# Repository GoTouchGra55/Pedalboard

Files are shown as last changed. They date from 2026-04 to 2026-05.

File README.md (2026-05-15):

# Multi-Effects Pedal Board

A custom multi-effects guitar pedal board combining several audio effects into one compact unit. Designed primarily as a learning project to explore analog audio circuits, signal processing, and embedded control systems (obv).

Also I needed effects pedals and those things are absurdly expensive ;')

---

## Features

- **Distortion & Overdrive** – From mild warmth to heavy saturation
- **Chorus** – Thickens and widens the sound
- **Tremolo** – Rhythmic volume modulation
- **Delay** – Adds echo and spatial depth

---

##  Signal Chain

Input -> Overdrive/Distortion -> Chorus -> Tremolo -> Delay -> Output

> _Note: Signal order can be adjusted depending on design preferences._

---

## Power Requirements

- **Input Voltage:** 9V DC (center-negative)
- **Power Supply:** Regulated recommended
- Includes onboard regulation and decoupling for noise reduction

---

## Hardware Overview

- Individual circuits for each effect
- Decoupling capacitors for stable operation

---

## I/O

- **Input Jack:** 1/4" mono
- **Output Jack:** 1/4" mono
- **DC Jack:** 9V input

---

## 3D View
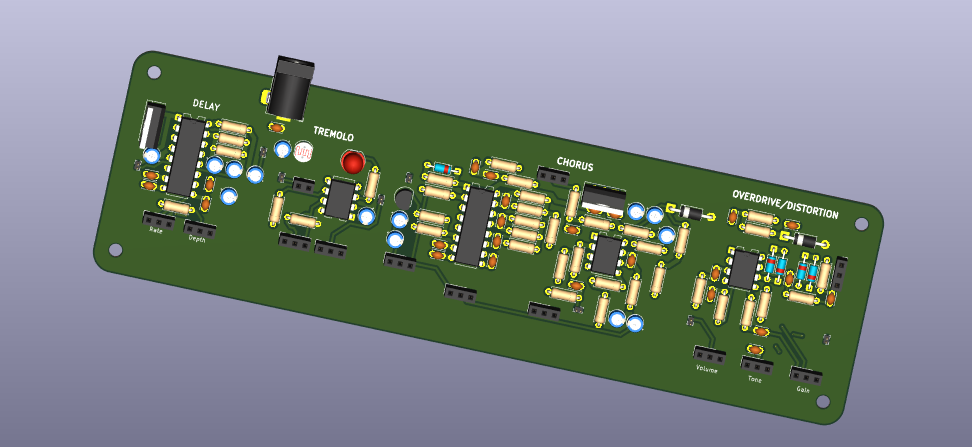
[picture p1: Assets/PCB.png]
PCB

---

## Routing
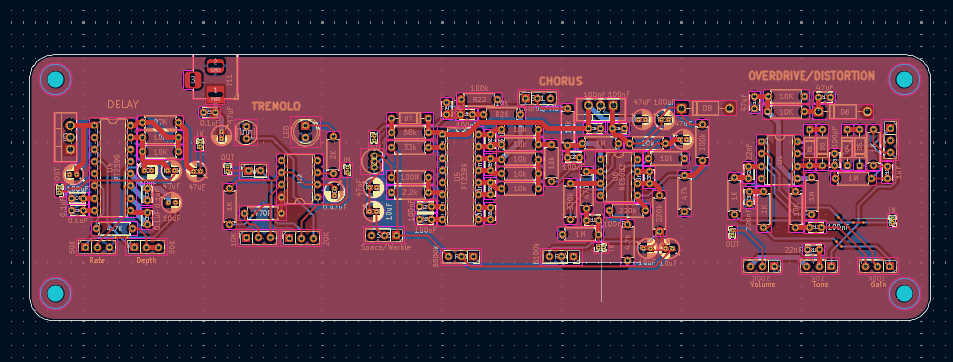
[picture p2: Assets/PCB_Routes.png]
PCB Routing


## BOM

| Component | Purpose | Qty | Total Cost (USD) | Distributor |
|---|---|---:|---:|---|
| Stomp Switch | Toggle each effect | 1 | 25.53 | Daraz Nepal |
| 50k Potentiometer | Used in circuit | 1 | 7.38 | Daraz Nepal |
| 20k Potentiometer | Used in circuit | 1 | 5.08 | Daraz Nepal |
| 2k Potentiometer | Used in circuit | 1 | 5.22 | Daraz Nepal |
| 10k Potentiometer | Used in circuit | 1 | 0.63 | Daraz Nepal |
| 100k Potentiometer | Used in circuit | 1 | 1.24 | Daraz Nepal |
| 500k Potentiometer | Used in circuit | 1 | 5.08 | Daraz Nepal |
| B100k Potentiometer | Used in circuit | 1 | 0.50 | Daraz Nepal |
| B500K Potentiometer | Used in circuit | 1 | 0.50 | Daraz Nepal |
| PCB | Houses all components | 1 | 8.20 | JLCPCB |
| DC Barrel Jack | Power input connector | 1 | 0.44 | Daraz Nepal |
| 1uF Capacitor | Charge storage/filtering | 1 | 0.88 | Daraz Nepal |
| 220nF Capacitor | Charge storage/filtering | 1 | 0.88 | Daraz Nepal |
| 100nF Capacitor | Charge storage/filtering | 1 | 1.82 | Daraz Nepal |
| Ceramic Capacitors Kit | Misc capacitor assortment | 1 | 7.91 | Daraz Nepal |
| Capacitor Kit | General purpose capacitors | 1 | 2.97 | Daraz Nepal |
| 2.2M Resistor | Current limiting | 1 | 0.66 | Daraz Nepal |
| Resistor Kit | General purpose resistors | 1 | 3.92 | Daraz Nepal |
| LDR | Tremolo light-dependent resistance | 1 | 2.27 | Daraz Nepal |
| LED | Status indication | 1 | 0.87 | Daraz Nepal |
| Voltage Regulator (7805) | Voltage regulation | 1 | 1.31 | Daraz Nepal |
| PT2399 IC | Delay/chorus processing IC | 1 | 2.36 | Daraz Nepal |
| LM555 Timer | PWM generation for tremolo | 1 | 2.00 | Daraz Nepal |
| NE5532 Op Amp | Chorus effect op amp | 1 | 1.78 | Daraz Nepal |
| TL072 | Gain/effects op amp | 1 | 1.69 | Daraz Nepal |
| Diode | One-way current flow | 1 | 0.40 | Daraz Nepal |
| Schottky Diode | Fast low-drop diode | 1 | 0.93 | Daraz Nepal |
| 1N4148 Diode | Signal diode | 1 | 0.27 | Daraz Nepal |
| 2N3904 Transistor | Signal filtering/amplification | 1 | 0.63 | Daraz Nepal |
| Guitar Jack Socket | Guitar/amp I/O connection | 2 | 2.07 | Daraz Nepal |

## Estimated Total Cost

**~$94.54 USD**

> Note: Prices may vary depending on shipping, stock availability, and quantity ordered.

---

## Suppliers

- Daraz Nepal
- JLCPCB

---

## Notes

- Passive component kits (capacitors/resistors) include multiple values and quantities.
- Potentiometer values may vary depending on the final pedal circuit tuning.
- PCB pricing is estimated from JLCPCB prototype manufacturing quotes.

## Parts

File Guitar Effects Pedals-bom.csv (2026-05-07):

Name | Purpose | Quantity | Total Cost (USD) | Link | Distributor
Stomp Switch | To toggle each effect | 1 | 25.53 | https://www.daraz.com.np/products/miwayer-510pcs-3pdt-footswitch-latching-stomp-switch-triple-pole-double-throw-9-pin-latching-push-button-for-diy-guitar-peda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 | Daraz Nepal
50k Potentiometer | Used in circuit | 1 | 7.38 | https://www.daraz.com.np/products/5pcs-wh148-3pin-20mm-potentiometer-b1k-b2k-b5k-b10k-b20k-b50k-b100k-b250k-b500k-b1m-1k-2k-5k-10k-20k-50k-100k-250k-500k-1m-i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 | Daraz Nepal
20k potentiometer | Used in circuit | 1 | 5.08 | https://www.daraz.com.np/products/5pcs-wh148-3pin-20mm-potentiometer-b1k-b2k-b5k-b10k-b20k-b50k-b100k-b250k-b500k-b1m-1k-2k-5k-10k-20k-50k-100k-250k-500k-1m-i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 | Daraz Nepal
2k Potentiometer | Used in circuit | 1 | 5.22 | https://www.daraz.com.np/products/5pcs-wh148-3pin-20mm-potentiometer-b1k-b2k-b5k-b10k-b20k-b50k-b100k-b250k-b500k-b1m-1k-2k-5k-10k-20k-50k-100k-250k-500k-1m-i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 | Daraz Nepal
10k Potentiometer | Used in circuit | 1 | 0.63 | https://www.daraz.com.np/products/10k-potentiometer5-pcs-i135751077-s1060884241.html?c=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 | Daraz Nepal
100k Potentiometer | Used in circuit | 1 | 1.24 | https://www.daraz.com.np/products/potentiometer-1k5k10k100k-5-pcs-i125469178-s1134645078.html?c=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 | Daraz Nepal
500k Potentiometer | Used in circuit | 1 | 5.08 | https://www.daraz.com.np/products/5pcs-wh148-3pin-20mm-potentiometer-b1k-b2k-b5k-b10k-b20k-b50k-b100k-b250k-b500k-b1m-1k-2k-5k-10k-20k-50k-100k-250k-500k-1m-i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 | Daraz Nepal
B100k Potentiometer | Used in circuit | 1 | 0.50 | https://www.daraz.com.np/products/2pcslot-wh148-b1k-b2k-b5k-b10k-b20k-b50k-b100k-b500k-3pin-15mm-shaft-amplifier-dual-stereo-potentiometer-1k-2k-5k-10k-50k-10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 | Daraz Nepal
B500K Potentiometer | Used in circuit | 1 | 0.50 | https://www.daraz.com.np/products/2pcslot-wh148-b1k-b2k-b5k-b10k-b20k-b50k-b100k-b500k-3pin-15mm-shaft-amplifier-dual-stereo-potentiometer-1k-2k-5k-10k-50k-10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 | Daraz Nepal
PCB | To house all the components | 1 | 8.20 | https://cart.jlcpcb.com/quote?spm=jlcpcb.Public.2006 | JLCPCB
DC Barrel Jack | To connect the board to a power supply | 1 | 0.44 | https://www.daraz.com.np/products/2-pcs-set-universal-dc-female-jack-connector-5v9v12v-i123504998-s1033563120.html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 | Daraz Nepal
1uF Capacitor | To store charge | 1 | 0.88 | https://www.daraz.com.np/products/100pcs-50v-monolithic-ceramic-capacitor-10pf-10uf-22pf-47nf-220nf-1nf-47uf-1uf-100nf-330nf-01uf-102-104-105-106-103-473-334-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 | Daraz Nepal
220nF capacitor | To store charge | 1 | 0.88 | https://www.daraz.com.np/products/100pcs-50v-monolithic-ceramic-capacitor-10pf-10uf-22pf-47nf-220nf-1nf-47uf-1uf-100nf-330nf-01uf-102-104-105-106-103-473-334-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 | Daraz Nepal
100nF Capactor | To store charge | 1 | 1.82 | https://www.daraz.com.np/products/100pcs-ceramic-capacitor-50v-1pf-100nf-01uf-104-47pf-10pf-22pf-33pf-47pf-100pf-101-220pf-10nf-330pf-470pf-1nf-103-47nf-473-i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 | Daraz Nepal
Ceramic capacitors | To store charge | 1 | 7.91 | https://www.daraz.com.np/products/7-value-components-big-kit-35mm-led-diodes-and-triodes-ceramics-electrolytic-ceramics-capacitors-metal-film-resistors-i41669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 | Daraz Nepal
Capacitors | To store charge | 1 | 2.97 | https://www.daraz.com.np/products/15-200-01-220-i182333371-s1214207392.html?c=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 | Daraz Nepal
2.2M Resistor | To resist current | 1 | 0.66 | https://www.daraz.com.np/products/50pcs-12w-1-metal-film-resistor-1r22m-100r-220r-330r-1k-15k-22k-33k-47k-10k-22k-47k-100k-100-220-330-1k5-2k2-3k3-4k7-ohm-i18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 | Daraz Nepal
Resistors | To resist current | 1 | 3.92 | https://www.daraz.com.np/products/30-kinds-14w-resistance-1-accuracy-metal-film-resistor-pack-600pcs-in-1-set-i156026363-s1122597672.html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 | Daraz Nepal
LDR | Used to change resistance according to light source for tremolo effect | 1 | 2.27 | https://www.daraz.com.np/products/50-5528-5-ldr5528-i182298738-s1214149089.html?c=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 | Daraz Nepal
LED | To indicate status of each section | 1 | 0.87 | https://www.daraz.com.np/products/led-5mm-mix-colors-pack-of-50-pcs-i129083282-s1037089095.html?c=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 | Daraz Nepal
Regulators | To regulate voltage | 1 | 1.31 | https://www.daraz.com.np/products/10pcs-l7805cv-to220-7805-l7805-lm7805-mc7805-a-220-new-original-chipset-ic-i182091744-s1213493606.html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 | Daraz Nepal
PT2399 IC | IC used in delay and chorus circuits | 1 | 2.36 | https://www.daraz.com.np/products/5-2399-2399-16-i182322725-s1214190239.html?c=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 | Daraz Nepal
LM555 Timer | Used to generate PWM pulses in the tremolo circuit | 1 | 2.00 | https://www.daraz.com.np/products/10-pces-lm555cn-dip8-lm555-dip-8-555cn-dip-novo-e-original-ic-i463052898-s2075470658.html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 | Daraz Nepal
NE5532 Op Amp | IC used in the chorus effect circuit | 1 | 1.78 | https://www.daraz.com.np/products/5532-5532-5532-i185487103-s1224283071.html?c=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 | Daraz Nepal
TL072 | IC used in the gain effects | 1 | 1.69 | https://www.daraz.com.np/products/10pcs-tl072cn-tl072-dip8-dip-new-original-in-stock-i463059995-s2075527623.html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 | Daraz Nepal
Diode | Acts as a one way valve | 1 | 0.40 | https://www.daraz.com.np/products/10-pcs-1n4007-diode-i129814544-s1037658646.html?c=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 | Daraz Nepal
Schottky Diode | Similar to a regular diode | 1 | 0.93 | https://www.daraz.com.np/products/100pcs-batch-of-schottky-rectifier-diodes-1n5817-1n5819-1n5399-1n4937-1n4004-1n4001-1n4007-uf4007-her107-fr207-fr157-fr107-r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 | Daraz Nepal
1N4148 Diode | Acts as a one way valve | 1 | 0.27 | https://www.daraz.com.np/products/1n4148-diode-pack-of-10-i129815432-s1037655901.html?c=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 | Daraz Nepal
2N3904 | Used in circuit for sound filtering | 1 | 0.63 | https://www.daraz.com.np/products/100pcslot-2n3904-2n3906-2n4403-2n2907-2n4401-2n2222-pn2222-2n5401-2n5551-to-92-to92-transistor-in-stock-i361437066-s15896176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 | Daraz Nepal
Cable socket | To connect the guitar and amplifier to the pedalboard | 2 | 2.07 | https://www.daraz.com.np/products/hosco-oj-50-mono-input-jack-socket-for-guitar-guitar-part-i121073063-s1032969614.html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 | Daraz Nepal

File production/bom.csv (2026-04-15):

Designator | Footprint | Quantity | Value | LCSC Part #
C1, C16 | C_Disc_D3.0mm_W2.0mm_P2.50mm | 2 | 22nF
C12 | C_Disc_D3.0mm_W2.0mm_P2.50mm | 1 | 220nF
C13, C19, C20, C21, C22, C27, C28, C34, C36 | C_Disc_D3.0mm_W2.0mm_P2.50mm | 9 | 100nF
C14 | C_Disc_D3.0mm_W2.0mm_P2.50mm | 1 | 100pF
C15 | C_Disc_D3.0mm_W2.0mm_P2.50mm | 1 | 1uF
C17, C18 | C_Disc_D3.0mm_W2.0mm_P2.50mm | 2 | 47uF
C2, C4, C5, C6, C7 | C_Disc_D3.0mm_W2.0mm_P2.50mm | 5 | 0.1uF
C23 | C_Disc_D3.0mm_W2.0mm_P2.50mm | 1 | 3.3nF
C24 | C_Disc_D3.0mm_W2.0mm_P2.50mm | 1 | 1nF
C25, C26, C33 | C_Disc_D3.0mm_W2.0mm_P2.50mm | 3 | 10nF
C3, PC10, PC11, PC29, PC35, PC38 | CP_Radial_D4.0mm_P1.50mm | 6 | 47uF
D1, D3, D4, D5, D7 | D_DO-35_SOD27_P7.62mm_Horizontal | 5 | 1N4148
D2 | LED_D5.0mm | 1 | LED
D6, D8 | D_DO-41_SOD81_P10.16mm_Horizontal | 2 | 1N5817
DEPTH1, RATE1 | PinSocket_1x03_P2.54mm_Vertical | 2 | 50K
GAIN1, VOLUME1 | PinSocket_1x03_P2.54mm_Vertical | 2 | 100K
J1, J10, J4, J8 | PinHeader_1x02_P1.00mm_Vertical | 4 | OUT
J11 | BarrelJack_Horizontal | 1 | Barrel_Jack_MountingPin
J2, J3, J7, J9 | PinHeader_1x02_P1.00mm_Vertical | 4 | IN
PC2 | CP_Radial_D4.0mm_P1.50mm | 1 | 0.47uF
PC3, PC37 | CP_Radial_D4.0mm_P1.50mm | 2 | 100uF
PC30, PC31, PC32, PC8, PC9 | CP_Radial_D4.0mm_P1.50mm | 5 | 10uF
Q1 | TO-92_Inline | 1 | 2N3904
R1 | R_Axial_DIN0207_L6.3mm_D2.5mm_P7.62mm_Horizontal | 1 | 2K
R10, R13, R18, R20 | R_Axial_DIN0207_L6.3mm_D2.5mm_P7.62mm_Horizontal | 4 | 1M
R11, R14, R4, R9 | R_Axial_DIN0207_L6.3mm_D2.5mm_P7.62mm_Horizontal | 4 | 1K
R12, R15, R16, R21, R23, R24, R25, R26, R27, R28, R29, R37, R38, R6, R8 | R_Axial_DIN0207_L6.3mm_D2.5mm_P7.62mm_Horizontal | 15 | 10K
R17 | R_Axial_DIN0207_L6.3mm_D2.5mm_P7.62mm_Horizontal | 1 | 470k
R19 | R_Axial_DIN0207_L6.3mm_D2.5mm_P7.62mm_Horizontal | 1 | 330k
R2 | R_LDR_4.9x4.2mm_P2.54mm_Vertical | 1 | VT93xx
R22, R39 | R_Axial_DIN0207_L6.3mm_D2.5mm_P7.62mm_Horizontal | 2 | 100k
R3 | R_Axial_DIN0207_L6.3mm_D2.5mm_P7.62mm_Horizontal | 1 | 470R
R30 | R_Axial_DIN0207_L6.3mm_D2.5mm_P7.62mm_Horizontal | 1 | 68k
R31 | R_Axial_DIN0207_L6.3mm_D2.5mm_P7.62mm_Horizontal | 1 | 33k
R32 | R_Axial_DIN0207_L6.3mm_D2.5mm_P7.62mm_Horizontal | 1 | 100R
R33 | R_Axial_DIN0207_L6.3mm_D2.5mm_P7.62mm_Horizontal | 1 | 2.2k
R34, R36 | R_Axial_DIN0207_L6.3mm_D2.5mm_P7.62mm_Horizontal | 2 | 220k
R35, R5 | R_Axial_DIN0207_L6.3mm_D2.5mm_P7.62mm_Horizontal | 2 | 4.7k
R40 | R_Axial_DIN0207_L6.3mm_D2.5mm_P7.62mm_Horizontal | 1 | 47k
R7 | R_Axial_DIN0207_L6.3mm_D2.5mm_P7.62mm_Horizontal | 1 | 27K
RV1 | PinSocket_1x03_P2.54mm_Vertical | 1 | 20K
RV2, TONE1 | PinSocket_1x03_P2.54mm_Vertical | 2 | 10K
RV3 | PinSocket_1x03_P2.54mm_Vertical | 1 | B500k
RV4 | PinSocket_1x03_P2.54mm_Vertical | 1 | B100k
SW1 | PinSocket_1x03_P2.54mm_Vertical | 1 | Chorus/Vibe
SW2 | PinSocket_1x02_P2.54mm_Vertical | 1 | SW_Nidec_CAS-120A1
SW3 | PinSocket_1x03_P2.54mm_Vertical | 1 | Space/Warble
TOGGLE1 | PinSocket_1x03_P2.54mm_Vertical | 1 | SW_Slide_DPDT
U1 | DIP-8_W7.62mm | 1 | TL072
U2 | DIP-8_W7.62mm | 1 | LM555xN
U3, U7 | TO-220-3_Vertical | 2 | LM7805_TO220
U4, U5 | DIP-16_W7.62mm | 2 | PT2399
U6 | DIP-8_W7.62mm | 1 | NE5532

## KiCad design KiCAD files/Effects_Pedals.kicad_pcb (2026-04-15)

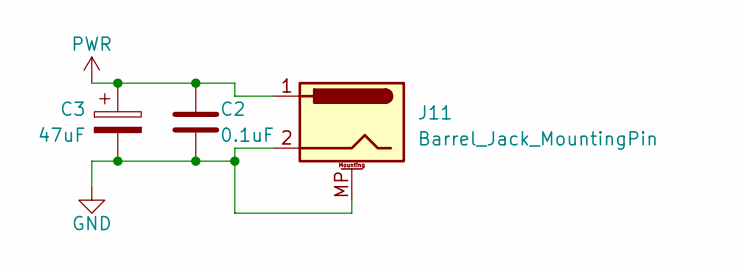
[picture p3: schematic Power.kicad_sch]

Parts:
C2: 0.1uF; C_Disc_D3.0mm_W2.0mm_P2.50mm
C3: 47uF; CP_Radial_D4.0mm_P1.50mm
J11: Barrel_Jack_MountingPin; BarrelJack_Horizontal

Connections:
GND: C2.2, C3.2, J11.2, J11.MP (MountPin); also elsewhere on the board
PWR: C2.1, C3.1, J11.1; also elsewhere on the board

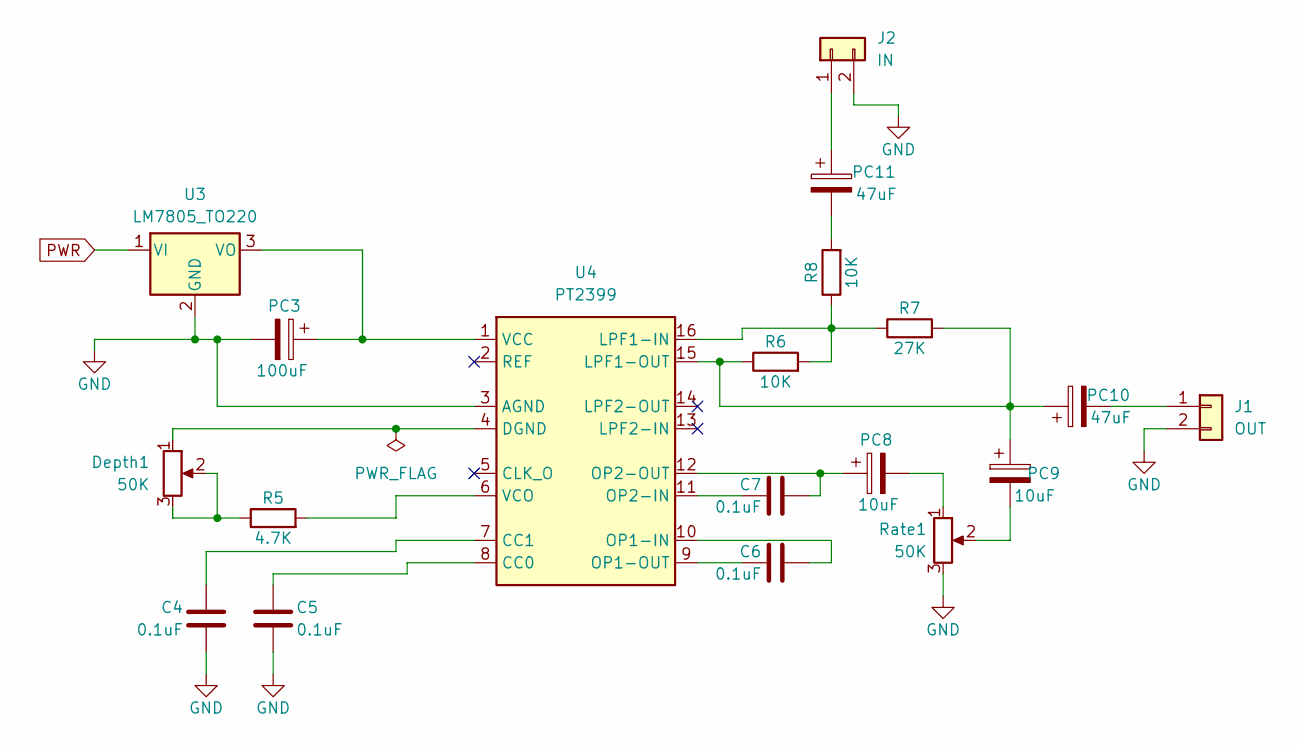
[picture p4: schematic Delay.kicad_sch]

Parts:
C4, C5, C6, C7: 0.1uF; C_Disc_D3.0mm_W2.0mm_P2.50mm
Depth1: 50K; PinSocket_1x03_P2.54mm_Vertical
J1: OUT; PinHeader_1x02_P1.00mm_Vertical
J2: IN; PinHeader_1x02_P1.00mm_Vertical
PC3: 100uF; CP_Radial_D4.0mm_P1.50mm
PC8, PC9: 10uF; CP_Radial_D4.0mm_P1.50mm
PC10, PC11: 47uF; CP_Radial_D4.0mm_P1.50mm
R5: 4.7K; R_Axial_DIN0207_L6.3mm_D2.5mm_P7.62mm_Horizontal
R6, R8: 10K; R_Axial_DIN0207_L6.3mm_D2.5mm_P7.62mm_Horizontal
R7: 27K; R_Axial_DIN0207_L6.3mm_D2.5mm_P7.62mm_Horizontal
Rate1: 50K; PinSocket_1x03_P2.54mm_Vertical
U3: LM7805_TO220; TO-220-3_Vertical
U4: PT2399; DIP-16_W7.62mm

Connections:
GND: C4.2, C5.2, J1.2, J2.2, PC3.2, Rate1.3, U3.2 (GND), U4.3 (AGND); also elsewhere on the board
unnamed: Depth1.2, Depth1.3, R5.1
unnamed: J1.1, PC10.2
unnamed: J2.1, PC11.1
unnamed: PC8.2, Rate1.1
unnamed: PC9.2, Rate1.2
unnamed: PC11.2, R8.2
unnamed: PC3.1, U3.3 (VO), U4.1 (VCC)
unnamed: C5.1, U4.8 (CC0)
unnamed: C4.1, U4.7 (CC1)
unnamed: Depth1.1, U4.4 (DGND)
unnamed: R6.2, R7.1, R8.1, U4.16 (LPF1-IN)
unnamed: PC9.1, PC10.1, R6.1, R7.2, U4.15 (LPF1-OUT)
unnamed: C6.2, U4.10 (OP1-IN)
unnamed: C6.1, U4.9 (OP1-OUT)
unnamed: C7.1, U4.11 (OP2-IN)
unnamed: C7.2, PC8.1, U4.12 (OP2-OUT)
unnamed: R5.2, U4.6 (VCO)
PWR: U3.1 (VI); also elsewhere on the board

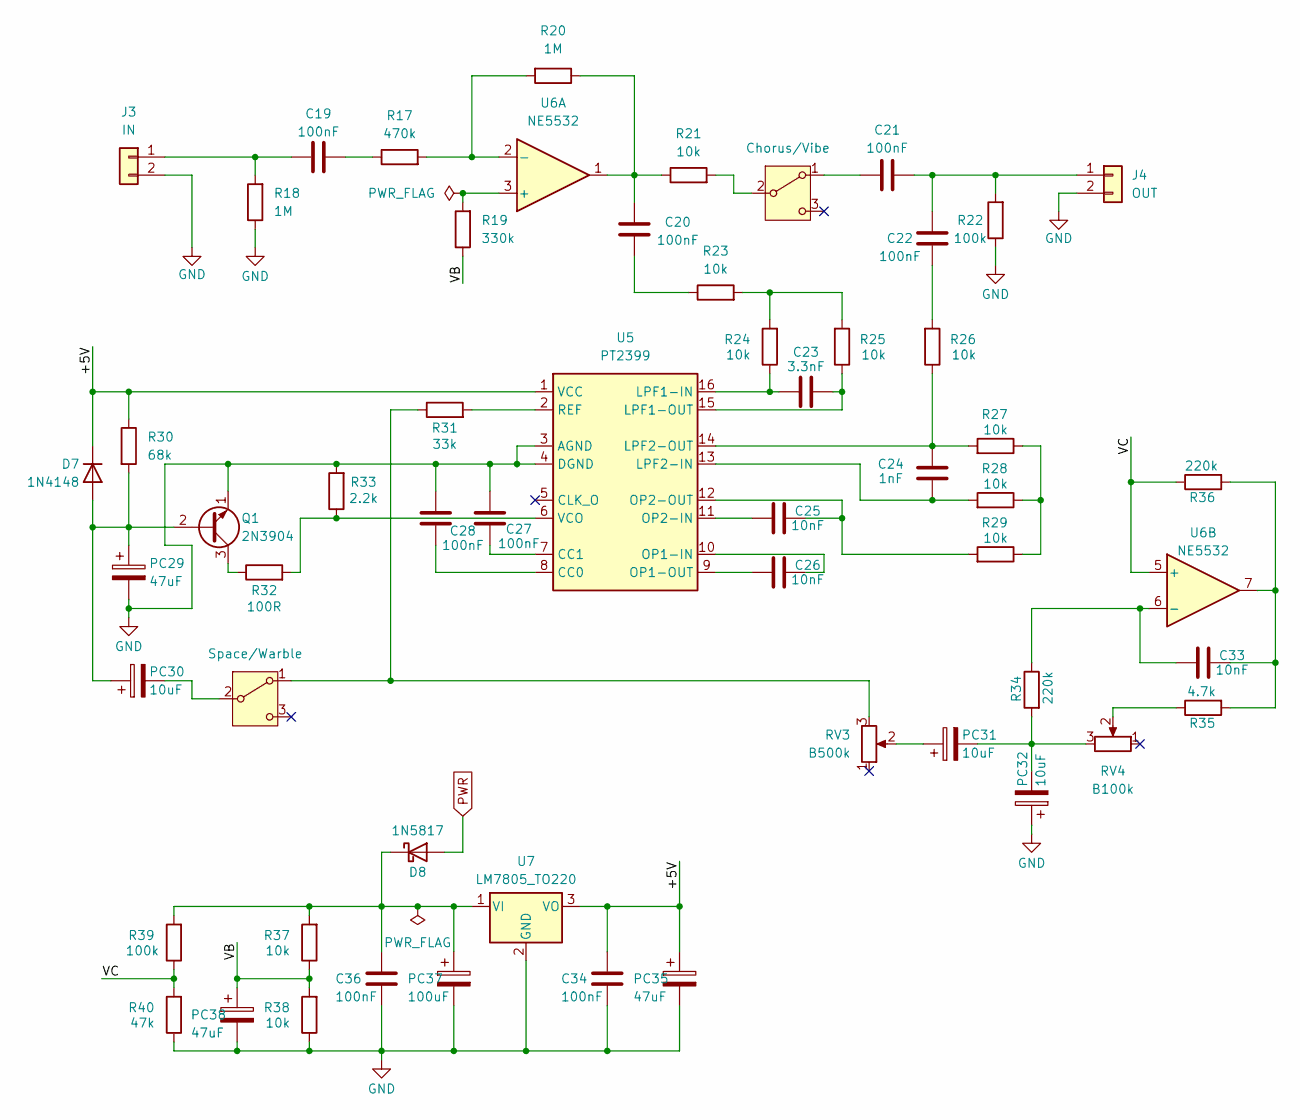
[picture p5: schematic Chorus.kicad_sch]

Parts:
C19, C20, C21, C22, C27, C28, C34, C36: 100nF; C_Disc_D3.0mm_W2.0mm_P2.50mm
C23: 3.3nF; C_Disc_D3.0mm_W2.0mm_P2.50mm
C24: 1nF; C_Disc_D3.0mm_W2.0mm_P2.50mm
C25, C26, C33: 10nF; C_Disc_D3.0mm_W2.0mm_P2.50mm
D7: 1N4148; D_DO-35_SOD27_P7.62mm_Horizontal
D8: 1N5817; D_DO-41_SOD81_P10.16mm_Horizontal
J3: IN; PinHeader_1x02_P1.00mm_Vertical
J4: OUT; PinHeader_1x02_P1.00mm_Vertical
PC29, PC35, PC38: 47uF; CP_Radial_D4.0mm_P1.50mm
PC30, PC31, PC32: 10uF; CP_Radial_D4.0mm_P1.50mm
PC37: 100uF; CP_Radial_D4.0mm_P1.50mm
Q1: 2N3904; TO-92_Inline
R17: 470k; R_Axial_DIN0207_L6.3mm_D2.5mm_P7.62mm_Horizontal
R18, R20: 1M; R_Axial_DIN0207_L6.3mm_D2.5mm_P7.62mm_Horizontal
R19: 330k; R_Axial_DIN0207_L6.3mm_D2.5mm_P7.62mm_Horizontal
R21, R23, R24, R25, R26, R27, R28, R29, R37, R38: 10k; R_Axial_DIN0207_L6.3mm_D2.5mm_P7.62mm_Horizontal
R22, R39: 100k; R_Axial_DIN0207_L6.3mm_D2.5mm_P7.62mm_Horizontal
R30: 68k; R_Axial_DIN0207_L6.3mm_D2.5mm_P7.62mm_Horizontal
R31: 33k; R_Axial_DIN0207_L6.3mm_D2.5mm_P7.62mm_Horizontal
R32: 100R; R_Axial_DIN0207_L6.3mm_D2.5mm_P7.62mm_Horizontal
R33: 2.2k; R_Axial_DIN0207_L6.3mm_D2.5mm_P7.62mm_Horizontal
R34, R36: 220k; R_Axial_DIN0207_L6.3mm_D2.5mm_P7.62mm_Horizontal
R35: 4.7k; R_Axial_DIN0207_L6.3mm_D2.5mm_P7.62mm_Horizontal
R40: 47k; R_Axial_DIN0207_L6.3mm_D2.5mm_P7.62mm_Horizontal
RV3: B500k; PinSocket_1x03_P2.54mm_Vertical
RV4: B100k; PinSocket_1x03_P2.54mm_Vertical
SW1: Chorus/Vibe; PinSocket_1x03_P2.54mm_Vertical
SW3: Space/Warble; PinSocket_1x03_P2.54mm_Vertical
U5: PT2399; DIP-16_W7.62mm
U6: NE5532; DIP-8_W7.62mm
U7: LM7805_TO220; TO-220-3_Vertical

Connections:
/Chorus/+5V: C34.1, D7.1 (K), PC35.1, R30.1, U5.1 (VCC), U7.3 (VO)
/Chorus/VB: PC38.1, R19.1, R37.1, R38.2
/Chorus/VC: R36.1, R39.1, R40.2, U6.5 (+)
GND: C27.1, C28.1, C34.2, C36.2, J3.2, J4.2, PC29.2, PC32.1, PC35.2, PC37.2, PC38.2, Q1.1 (E), R18.1, R22.1, R33.2, R38.1, R40.1, U5.3 (AGND), U5.4 (DGND), U7.2 (GND); also elsewhere on the board
unnamed: C19.2, R17.1
unnamed: C20.1, R23.1
unnamed: C20.2, R20.1, R21.1, U6.1
unnamed: C22.2, R26.2
unnamed: C33.1, R35.2, R36.2, U6.7
unnamed: D7.2 (A), PC29.1, PC30.1, Q1.2 (B), R30.2
unnamed: C36.1, D8.1 (K), PC37.1, R37.2, R39.2, U7.1 (VI)
unnamed: C19.1, J3.1, R18.2
unnamed: C21.1, C22.1, J4.1, R22.2
unnamed: PC31.1, RV3.2
unnamed: PC31.2, PC32.2, R34.2, RV4.3
unnamed: Q1.3 (C), R32.1
unnamed: R23.2, R24.2, R25.2
unnamed: R27.1, R28.1, R29.1
unnamed: R35.1, RV4.2
unnamed: C21.2, SW1.1 (A)
unnamed: R21.2, SW1.2 (B)
unnamed: R31.1, RV3.3, SW3.1 (A)
unnamed: PC30.2, SW3.2 (B)
unnamed: C28.2, U5.8 (CC0)
unnamed: C27.2, U5.7 (CC1)
unnamed: C23.2, R24.1, U5.16 (LPF1-IN)
unnamed: C23.1, R25.1, U5.15 (LPF1-OUT)
unnamed: C24.2, R28.2, U5.13 (LPF2-IN)
unnamed: C24.1, R26.1, R27.2, U5.14 (LPF2-OUT)
unnamed: C26.1, U5.10 (OP1-IN)
unnamed: C26.2, U5.9 (OP1-OUT)
unnamed: C25.2, U5.11 (OP2-IN)
unnamed: C25.1, R29.2, U5.12 (OP2-OUT)
unnamed: R31.2, U5.2 (REF)
unnamed: R32.2, R33.1, U5.6 (VCO)
unnamed: R19.2, U6.3 (+)
unnamed: R17.2, R20.2, U6.2 (-)
unnamed: C33.2, R34.1, U6.6 (-)
PWR: D8.2 (A); also elsewhere on the board

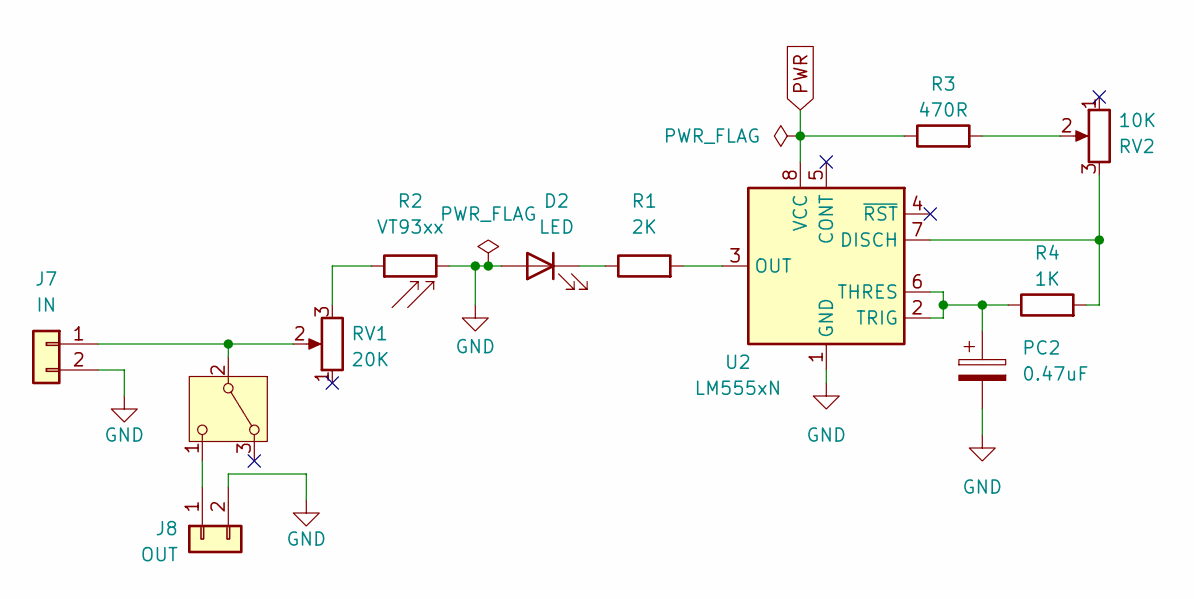
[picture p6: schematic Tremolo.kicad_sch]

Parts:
D2: LED; LED_D5.0mm
J7: IN; PinHeader_1x02_P1.00mm_Vertical
J8: OUT; PinHeader_1x02_P1.00mm_Vertical
PC2: 0.47uF; CP_Radial_D4.0mm_P1.50mm
R1: 2K; R_Axial_DIN0207_L6.3mm_D2.5mm_P7.62mm_Horizontal
R2: VT93xx; R_LDR_4.9x4.2mm_P2.54mm_Vertical
R3: 470R; R_Axial_DIN0207_L6.3mm_D2.5mm_P7.62mm_Horizontal
R4: 1K; R_Axial_DIN0207_L6.3mm_D2.5mm_P7.62mm_Horizontal
RV1: 20K; PinSocket_1x03_P2.54mm_Vertical
RV2: 10K; PinSocket_1x03_P2.54mm_Vertical
SW2: SW_Nidec_CAS-120A1; PinSocket_1x02_P2.54mm_Vertical
U2: LM555xN; DIP-8_W7.62mm

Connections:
GND: D2.2 (A), J7.2, J8.2, PC2.2, R2.2, U2.1 (GND); also elsewhere on the board
unnamed: D2.1 (K), R1.1
unnamed: J7.1, RV1.2, SW2.2 (B)
unnamed: J8.1, SW2.1 (C)
unnamed: R2.1, RV1.3
unnamed: R3.2, RV2.2
unnamed: R4.2, RV2.3, U2.7 (DISCH)
unnamed: R1.2, U2.3 (OUT)
unnamed: PC2.1, R4.1, U2.2 (TRIG), U2.6 (THRES)
PWR: R3.1, U2.8 (VCC); also elsewhere on the board

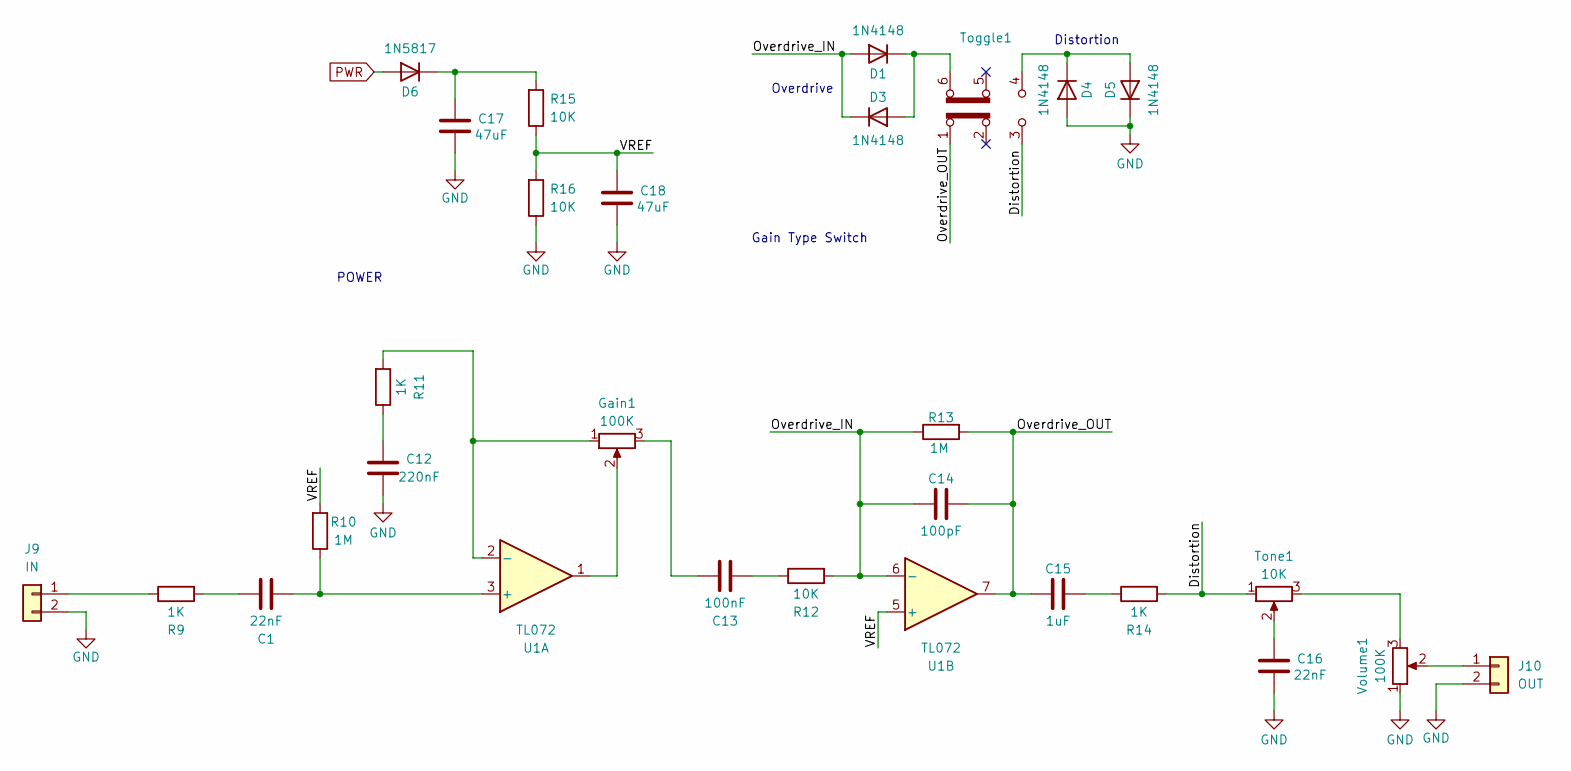
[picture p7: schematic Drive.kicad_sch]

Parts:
C1, C16: 22nF; C_Disc_D3.0mm_W2.0mm_P2.50mm
C12: 220nF; C_Disc_D3.0mm_W2.0mm_P2.50mm
C13: 100nF; C_Disc_D3.0mm_W2.0mm_P2.50mm
C14: 100pF; C_Disc_D3.0mm_W2.0mm_P2.50mm
C15: 1uF; C_Disc_D3.0mm_W2.0mm_P2.50mm
C17, C18: 47uF; C_Disc_D3.0mm_W2.0mm_P2.50mm
D1, D3, D4, D5: 1N4148; D_DO-35_SOD27_P7.62mm_Horizontal
D6: 1N5817; D_DO-41_SOD81_P10.16mm_Horizontal
Gain1: 100K; PinSocket_1x03_P2.54mm_Vertical
J9: IN; PinHeader_1x02_P1.00mm_Vertical
J10: OUT; PinHeader_1x02_P1.00mm_Vertical
R9, R11, R14: 1K; R_Axial_DIN0207_L6.3mm_D2.5mm_P7.62mm_Horizontal
R10, R13: 1M; R_Axial_DIN0207_L6.3mm_D2.5mm_P7.62mm_Horizontal
R12, R15, R16: 10K; R_Axial_DIN0207_L6.3mm_D2.5mm_P7.62mm_Horizontal
Toggle1: SW_Slide_DPDT; PinSocket_1x03_P2.54mm_Vertical
Tone1: 10K; PinSocket_1x03_P2.54mm_Vertical
U1: TL072; DIP-8_W7.62mm
Volume1: 100K; PinSocket_1x03_P2.54mm_Vertical

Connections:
/OD_Dist/Distortion: R14.2, Toggle1.3 (C), Tone1.1
/OD_Dist/Overdrive_IN: C14.2, D1.2 (A), D3.1 (K), R12.2, R13.1, U1.6 (-)
/OD_Dist/Overdrive_OUT: C14.1, C15.2, R13.2, Toggle1.1 (A), U1.7
/OD_Dist/VREF: C18.1, R10.2, R15.1, R16.2, U1.5 (+)
GND: C12.2, C16.2, C17.2, C18.2, D4.2 (A), D5.1 (K), J9.2, J10.2, R16.1, Volume1.1; also elsewhere on the board
unnamed: C1.2, R9.2
unnamed: C12.1, R11.1
unnamed: C13.1, R12.1
unnamed: C13.2, Gain1.3
unnamed: C15.1, R14.1
unnamed: C16.1, Tone1.2
unnamed: D1.1 (K), D3.2 (A), Toggle1.6 (C)
unnamed: D4.1 (K), D5.2 (A), Toggle1.4 (A)
unnamed: C17.1, D6.1 (K), R15.2
unnamed: Gain1.2, U1.1
unnamed: J9.1, R9.1
unnamed: J10.1, Volume1.2
unnamed: Tone1.3, Volume1.3
unnamed: C1.1, R10.1, U1.3 (+)
unnamed: Gain1.1, R11.2, U1.2 (-)
PWR: D6.2 (A); also elsewhere on the board

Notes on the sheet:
Distortion
Gain Type Switch
POWER
Overdrive

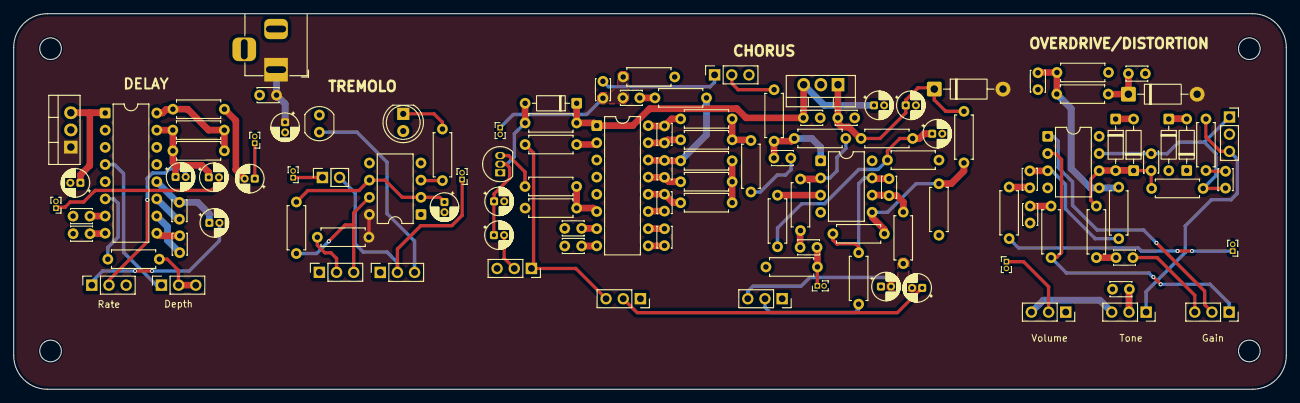
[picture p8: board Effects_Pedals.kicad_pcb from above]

Board: 2 copper layers, 188.2 x 55.5 mm, 118 parts (0 on the bottom side), 83 nets.

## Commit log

2026-04-15 Add new files
    [Effects_Pedals.kicad_pcb, Effects_Pedals.kicad_sch, bom.csv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]
2026-05-07 Add bom and update readme
    [Guitar Effects Pedals-bom.csv]
